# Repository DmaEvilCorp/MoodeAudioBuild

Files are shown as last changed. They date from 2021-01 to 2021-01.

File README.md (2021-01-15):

# MoodeAudioBuild
Just a build report, may help or give idea to other people.
Using a Raspberry Pi 2b+ (512mb ram) with MoodeAudio 6.7.1 on a 32GB MicroSD + AudioPhonics DAC ES9023 V1.
http://moodeaudio.org/

Case Hammond 1455T2202BK (220x165x51.5mm) black aluminium.
Front and back are in plastic, much easier for working.
I've used FrontPanel from Schaeffer to make the design.

Power supply :
- Toroidal transformer 2x115vac / 2x15vac 18VA (modified to 1x15vac / 1x8vac).
- 5vdc regulator with a LD1805 (2x2200uF) (BYV-100 Diode).

Power supply controler :
- Attiny 13A who control 2 relay.
  - First relay control de power to the rpi.
  - Second relay send a short contact to a GPIO witch is configure to shutdown the rpi.
  - 1 button (First push = Power ON / Second long push = Power OFF after 1 min).
- See Kicad schematic & Arduino Code (Using MicroCore https://github.com/MCUdude/MicroCore) & Usbasp for programming.

Display :
- Using a HD44780 compatible display 2x20.
- Drive by pydPiper https://github.com/dhrone/pydPiper.
- pydPiper is running outside of docker for performance (pi2 too slow).
  - Autostart in /etc/rc.local by adding the line (at the end of the file) sudo sh /home/pi/pydpiper.sh &
  - pydpiper.sh simply do :
    - cd /home/pi/pydPiper
    - sudo python pydPiper.py
    
Todo :
- Upgrade to MoodeAudio 7.x.
- Resolve GPIO bug.
- Print front panel to cover the screw.

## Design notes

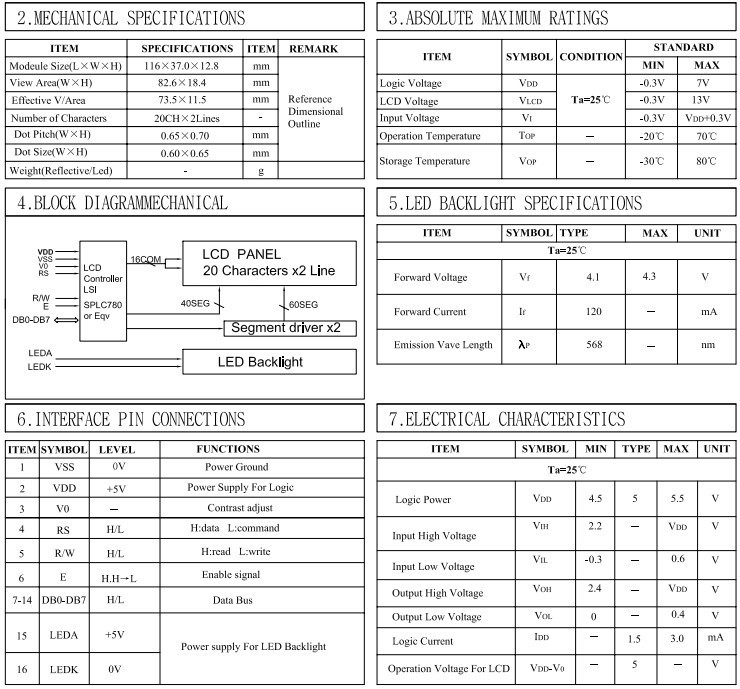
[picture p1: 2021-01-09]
HD44780 Pinout.jpg

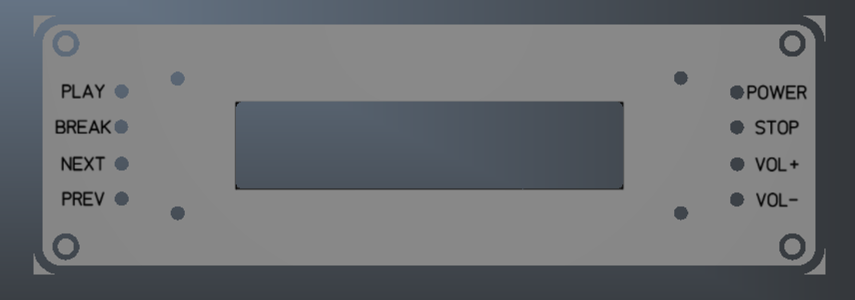
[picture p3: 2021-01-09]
FrontCase.PNG

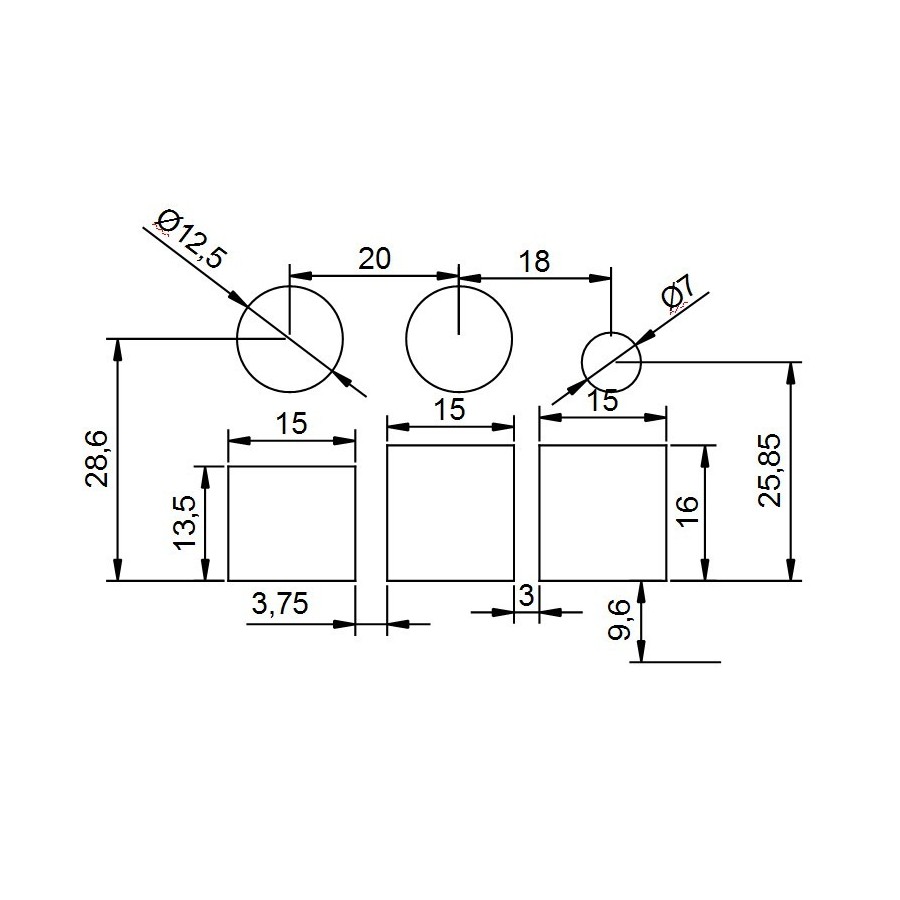
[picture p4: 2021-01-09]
audiophonics-i-sabre-dac-es9023-v2-tcxo-raspberry-pi-20-a-b-i2s.jpg

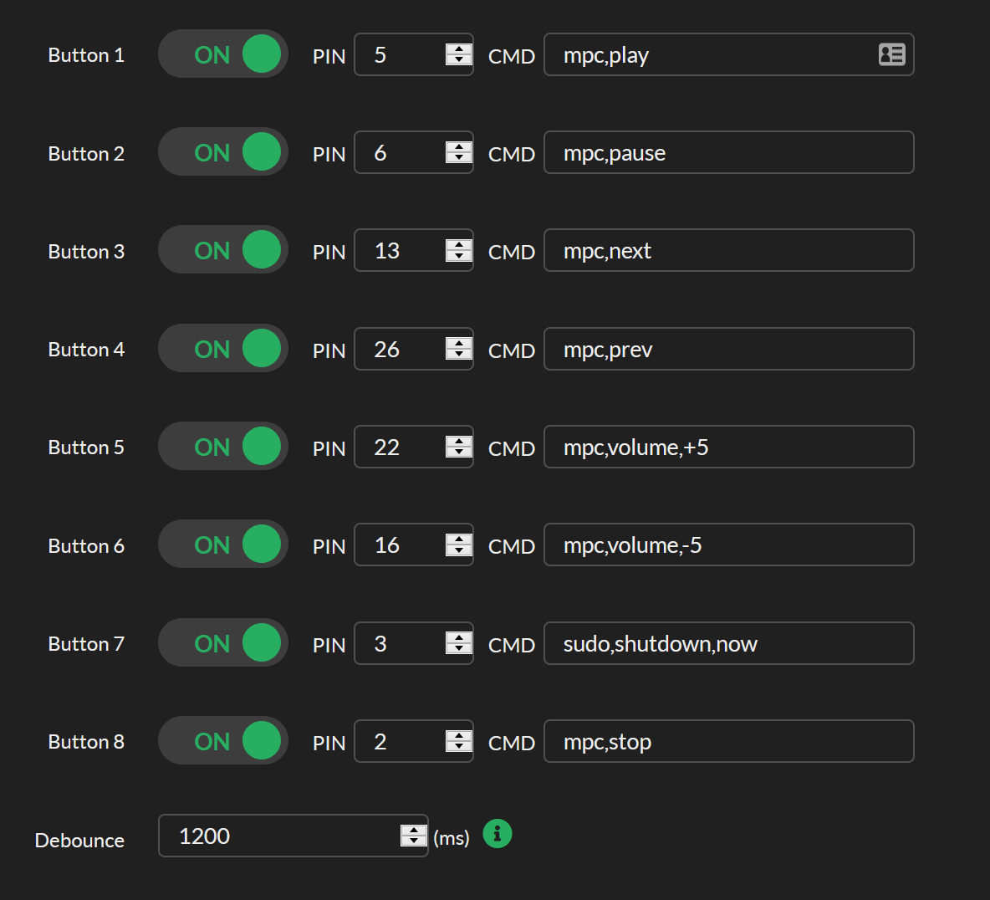
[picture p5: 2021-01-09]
GPIO Config.PNG

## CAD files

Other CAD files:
Hammond Case.dwg

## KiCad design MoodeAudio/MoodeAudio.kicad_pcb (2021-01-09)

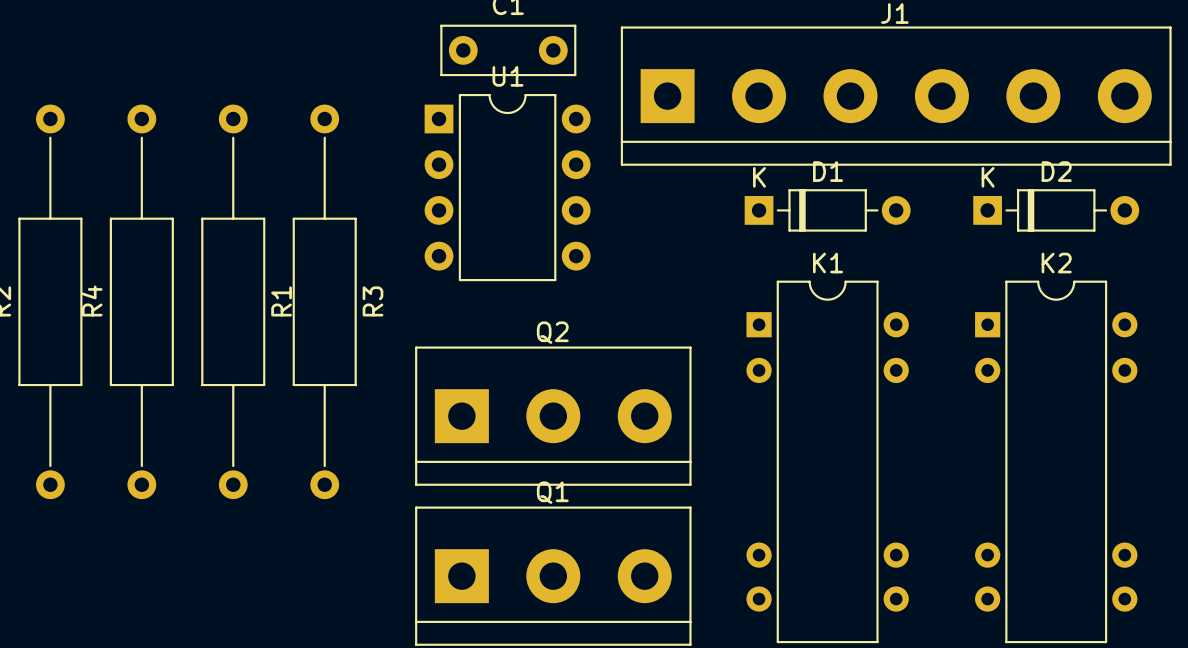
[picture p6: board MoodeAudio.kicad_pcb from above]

Board: 2 copper layers, 13 parts (0 on the bottom side), 14 nets, no tracks yet.

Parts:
C1: 100nF; C_Rect_L7.2mm_W2.5mm_P5.00mm_FKS2_FKP2_MKS2_MKP2
D1, D2: 1N4148; D_DO-35_SOD27_P7.62mm_Horizontal
J1: Conn_01x06_Female; TerminalBlock_bornier-6_P5.08mm
K1, K2: DIPxx-1Axx-11x; Relay_StandexMeder_DIP_LowProfile
Q1, Q2: Q_NPN_BCE; TerminalBlock_bornier-3_P5.08mm
R1, R2, R3, R4: 10K; R_Axial_DIN0309_L9.0mm_D3.2mm_P20.32mm_Horizontal
U1: ATtiny13-20PU; DIP-8_W7.62mm

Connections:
GND: C1.1, J1.2, Q1.3, Q2.3, U1.4
unnamed: C1.2, D1.1, D2.1, J1.1, K1.6, K1.7, K1.8, K2.6, R1.1, R3.1, U1.8
unnamed: D1.2, K1.2, Q1.2
unnamed: D2.2, K2.2, Q2.2
unnamed: J1.3, R3.2
unnamed: J1.4, U1.7
unnamed: J1.5, K2.7, K2.8
unnamed: J1.6, K2.1, K2.14
unnamed: K1.1, K1.14
unnamed: Q1.1, R2.1
unnamed: Q2.1, R4.1
unnamed: R1.2, U1.1
unnamed: R2.2, U1.6
unnamed: R4.2, U1.5

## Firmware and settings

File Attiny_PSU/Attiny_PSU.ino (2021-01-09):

// constants won't change. They're used here to set pin numbers:
const int BUTTON_PIN = 2;  // the number of the pushbutton pin
const int RELAY_PIN = 0; // the number of the relay pin
const int RESET_RASPBERRY = 1;
const int ledstatus = 4;
unsigned long OnDelay = 2000;  // on delay before switch on relay
unsigned long OffDelay = 20000;    // off delay before switch off the relay

// variables will change:
int TimeOn = 2;
int TimeOff = 30;
int buttonState = LOW;         // variable for reading the pushbutton status
int relayState = LOW;

void setup() {
  // put your setup code here, to run once:
  // initialize the relay pin as an output:
  pinMode(RELAY_PIN, OUTPUT);
  pinMode(RESET_RASPBERRY, OUTPUT);
  pinMode(ledstatus, OUTPUT);
  // initialize the pushbutton pin as an input:
  pinMode(BUTTON_PIN, INPUT);
  // Init led
  relayState = LOW;
}
  
void loop() {
  // read the state of the pushbutton value:
  buttonState = digitalRead(BUTTON_PIN);

   // check if the pushbutton is pressed and if relay switched off
   if ((buttonState == HIGH) && (relayState == LOW)){
   // turn relay on after 1 second:
   delay(1000);
   buttonState = digitalRead(BUTTON_PIN);
        if ((buttonState == HIGH) && (relayState == LOW)){
          digitalWrite(RELAY_PIN, HIGH);
          delay(500);
          relayState = HIGH;
      }
  // read the state of the pushbutton value again:
  buttonState = digitalRead(BUTTON_PIN);
  
  }
  // check if the pushbutton is pressed and if relay is switched on
  if ((buttonState == HIGH) && (relayState == HIGH)){
    delay(2000); // Safety
    buttonState = digitalRead(BUTTON_PIN);
    if ((buttonState == HIGH) && (relayState == HIGH)){
      digitalWrite(RESET_RASPBERRY, HIGH); // Send shutdown signal to GPIO
      delay(1200);
      digitalWrite(RESET_RASPBERRY, LOW);
      delay(30000);
      digitalWrite(RELAY_PIN, LOW);
      relayState = LOW;
    }
  }
}
